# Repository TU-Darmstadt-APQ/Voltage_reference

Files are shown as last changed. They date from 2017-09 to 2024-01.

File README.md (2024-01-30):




# LM399 Sub-ppm Reference Voltage

This repository contains the KiCAD PCB project files for a sub-ppm temperature coefficient __negative voltage reference__ used in the [digital laser driver design](https://github.com/TU-Darmstadt-APQ/DgDrive).

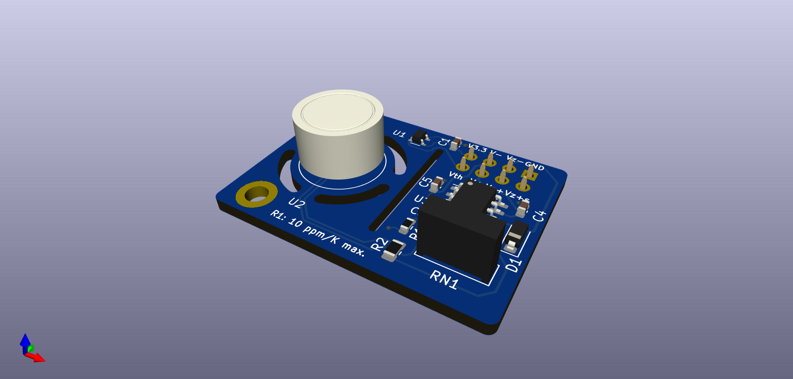
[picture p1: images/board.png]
LM399 reference board


## Circuit description

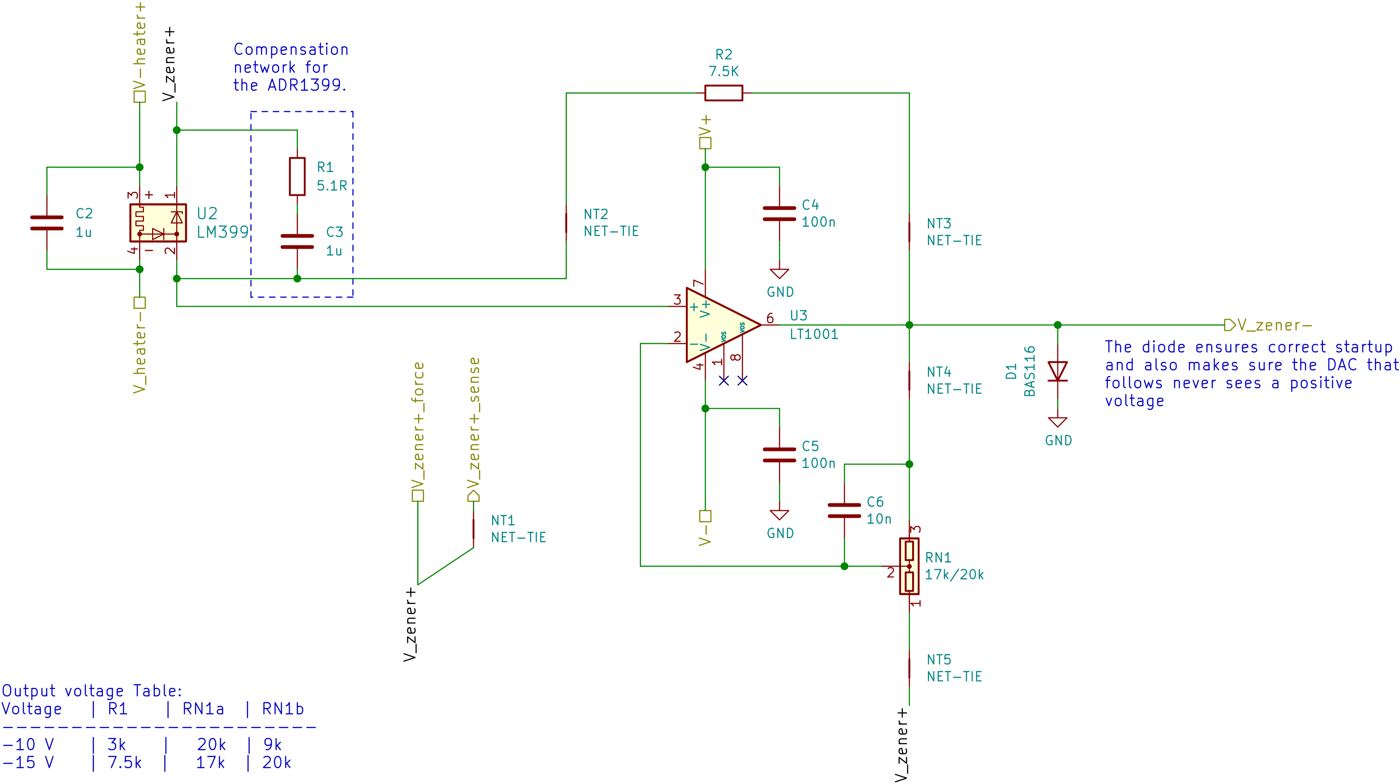
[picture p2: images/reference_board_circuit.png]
LM399 reference board circuit


This circuit utilizes the excellent [LM399](https://www.analog.com/en/products/lm399.html) voltage reference and outputs an amplified voltage of either -10 V or -15 V. There is no option to trim the output voltage as the absolute value is not that important, but stability is. The output voltage will be 10 V / 15 V __below__ the positive pin of the Zener diode.

The design is a self-biased circuit, which means the Zener diode bias current is produced by the Zener voltage and therefore as stable as the reference (neglecting the influence of the bias current on the Zener voltage as it is negligible). In order to keep the Zener self-heating of the diode as low possible, a Zener current of a little more than 1 mA was chosen for the  [LM399](https://www.analog.com/en/products/lm399.html).

Reference table for choosing the resistor values:

|Voltage | R1 | RN1 |
|---|---|---|
|-10 V | 3k | 20k /  9k  |
|-15 V | 7.89k | 17k / 20k |

Different values are possible as well, but these values were readily available on Farnell/Mouser. When choosing a value for R1, choose a value as close as possible but always __less than or equal__ to the value given. This ensures, that the Zener current is at least 1 mA.

Single supply operation is possible as long the output voltage is larger than 0.1 V.

## Design Files
### For production
The design files required for the PCB production and assembly can be found on the [releases](../../releases) page and include the following resources:

- Schematics as a PDF
- Gerber files
- Pick & place position files
- Bill of materials as a CSV file and also as an interactive HTML version

The latest revision of those files can be found [here](../../releases/latest).

#### Variants
Two variants of the design files are provided for the user. There is a so-called *default* variant and a *PCBA* (Printed Circuit Board Assembly) variant.

##### Default variant
The default variant contains the full set of components and should be used for hand assembly when a set of binned and tested components is available. It includes both the Zener reference and resistive divider which need to be tested for popcorn noise and drift before installation.

##### PCBA variant
The PCBA variant should be used when sending the boards to the PCB manufacturer for assembly as they do not contain the [LM399](https://www.analog.com/en/products/lm399.html)/[ADR1399](https://www.analog.com/en/products/adr1399.html) Zener reference and the precision resistor array to amplify the output voltage. These components need to be binned prior to installation and should therefore not be placed by the board house.

### For editing
To work on the [KiCad](https://www.kicad.org/) design files, a number of external libraries are needed. Those libraries show up as empty folders in the zip file, because they are not included in the release, but must be downloaded separately from the links given [below](#related-repositories). This can be avoided by checking out the whole repository using git. This way the libraries will be downloaded as well. Use the following command to clone the git repository along with the submodules  using the `--recurse-submodules` flag.
```
git clone --recurse-submodules https://github.com/TU-Darmstadt-APQ/Voltage_reference
```

## Related Repositories
See the following repositories for more information as these are part of the [design files](#design Files).

- [KiCad footprints](https://github.com/PatrickBaus/footprints.pretty)
- [KiCAD 3D models](https://github.com/PatrickBaus/footprints.3dshapes)
- [KiCAD schematic libraries](https://github.com/PatrickBaus/KiCad-libraries)

## Versioning
I use [SemVer](http://semver.org/) for versioning. For the versions available, see the [tags](../../tags) available for this repository.

- MAJOR versions in this context mean a breaking change to the external interface of the hardware like different connectors or functions.
- MINOR versions contain changes to the hardware that only affect the inner workings of the circuit, but otherwise the performance is unaffected.
- PATCH versions do not affect the schematics or invalidate older bill of materials. These changes may include updated components (to replace obsolete parts for example), an updated silkscreen, or fixed typos.

## License
This work is released under the CERN-OHL-W
See [https://ohwr.org/cern_ohl_w_v2.pdf](https://ohwr.org/cern_ohl_w_v2.pdf) or the included LICENSE file for more information.

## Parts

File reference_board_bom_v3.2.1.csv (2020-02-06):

Component | Quantity Per PCB | References | Value | MFN | PN | Description | Footprint | Note | Alternative
1 | 3 | C1-C3 | 100n | Murata | GRM31C5C1H104JA01L | Unpolarized capacitor | C_1206_3216Metric
2 | 1 | C4 | 100n | Murata | GRM188R71H104KA93D | Unpolarized capacitor | C_0603_1608Metric
3 | 1 | D1 | BAS116 | Nexperia | BAS116GWJ | Diode | D_SOD-123 | Use a plastic package to eliminate light sensitivity
4 | 1 | J1 | CONN_02X04 | Amphenol | 87606-804LF | Generic connector, double row, 02x04, odd/even pin numbering scheme (row 1 odd numbers, row 2 even numbers), script generated (kicad-library-utils/schlib/autogen/connector/) | PinSocket_2x04_P2.54mm_Vertical
5 | 1 | R3 | 10k | Susumu | RR0816P-103-D | Resistor | R_0603_1608Metric
6 | 1 | R2 | 30k | Susumu | RR0816P-303-D | Resistor | R_0603_1608Metric
7 | 1 | R1 | 7.5K | Welwyn | PCF0805-13-7K5-B-T1 | Resistor | R_0805_2012Metric |  | Panasonic ERA-6ARB752V
8 | 1 | RN1 | 17k/20k | Vishay | Y1691V0689BB9L | Voltage divider | Vishay_300144 | Vishay 300144Z, 0.1% abs. tol. 0.1% ratio tol.
9 | 1 | U2 | LM399 | Analog Devices | LM399AH | Precision Reference, 6.95V, Buried Zener Diode with Thermal Shielding Can | TO-46-4_ThermalShield | Use a TE 8060-1G12 socket to mount diodes for burn-in
10 | 1 | U3 | LT1001 | Analog Devices | LT1001CS8 | 70MHz, 1000V/µs Operational Amplifier, DIP-8/SOIC-8 | SOIC-8_3.9x4.9mm_P1.27mm |  | TI OPA277U
11 | 1 | U1 | TMP236 | Texas Instruments | TMP236A2DCKT | Analog thermistor temperature sensor, ±2.5C accuracy, -55C to +130C, SC-70-5 | SOT-353_SC-70-5
Component Groups: | 11
Component Count: | 13
Fitted Components: | 13
Number of PCBs: | 1
Total components: | 13
Schematic Version: | v3.2.1
Schematic Date: | 2020-02-06
PCB Variant: | default
BoM Date: | 2020-02-06T17:09:21 CET
Schematic Source: | /home/maat/Documents/Uni/Physik/Phd/DgDrive/KiCAD/reference_board/reference_board.sch
KiCad Version: | Eeschema 5.1.5

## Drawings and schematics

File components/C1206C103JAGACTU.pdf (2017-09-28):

# KEMET Part Number: C1206C103JAGACTU

# (C1206C103JAGAC7800)

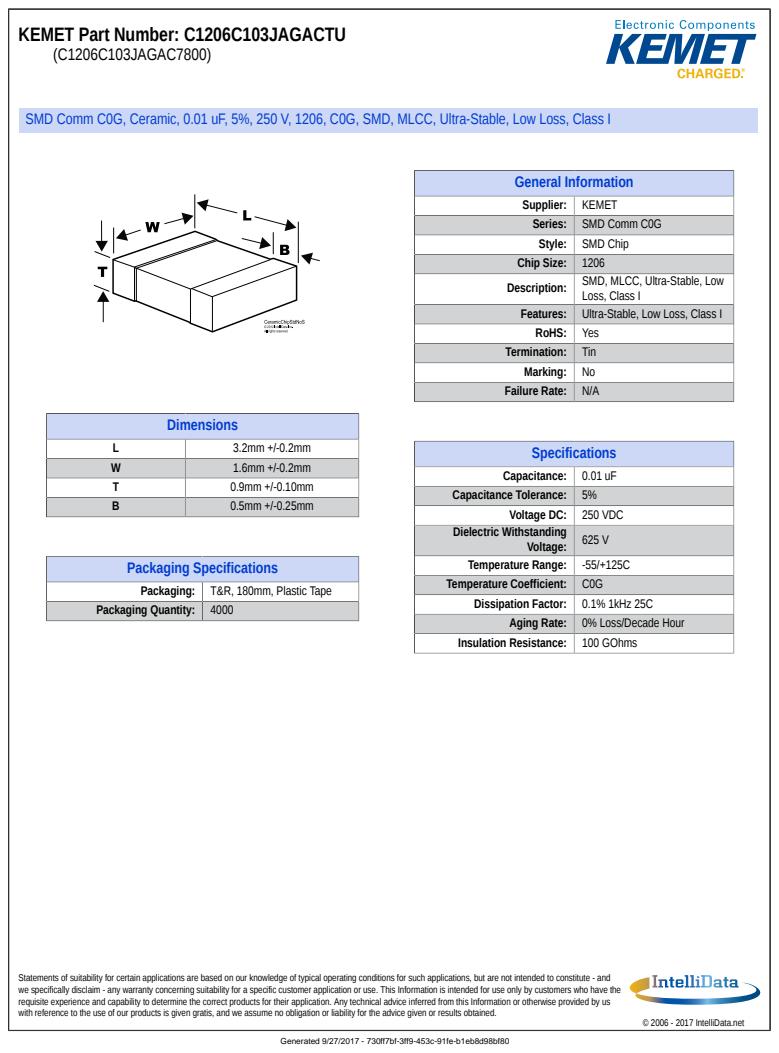
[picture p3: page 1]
Generated 9/27/2017 - 730ff7bf-3ff9-453c-91fe-b1eb8d98bf80; Dimensions; Packaging Specifications; General Information; Specifications; Temperature Range:; © 2006 - 2017 IntelliData.net

SMD Comm C0G, Ceramic, 0.01 uF, 5%, 250 V, 1206, C0G, SMD, MLCC, Ultra-Stable, Low Loss, Class I

Supplier: | KEMET
Series: | SMD Comm C0G
Style: | SMD Chip
Chip Size: | 1206
Description: | SMD, MLCC, Ultra-Stable, Low Loss, Class I

Features: | Ultra-Stable, Low Loss, Class I
RoHS: | Yes
Termination: | Tin
Marking: | No
Failure Rate: | N/A

W 1.6mm +/-0.2mm
T 0.9mm +/-0.10mm
B 0.5mm +/-0.25mm

Capacitance: | 0.01 uF

Capacitance Tolerance: | 5%

Voltage DC: | 250 VDC

Dielectric Withstanding Voltage: | 625 V

Packaging: | T&R, 180mm, Plastic Tape
Packaging Quantity: | 4000

Temperature Coefficient: | C0G
Dissipation Factor: | 0.1% 1kHz 25C
Aging Rate: | 0% Loss/Decade Hour

Insulation Resistance: | 100 GOhms

Statements of suitability for certain applications are based on our knowledge of typical operating conditions for such applications, but are not intended to constitute - and
we specifically disclaim - any warranty concerning suitability for a specific customer application or use. This Information is intended for use only by customers who have the
requisite experience and capability to determine the correct products for their application. Any technical advice inferred from this Information or otherwise provided by us
with reference to the use of our products is given gratis, and we assume no obligation or liability for the advice given or results obtained.

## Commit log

2017-08-21 Updated readme with a circuit description Fixed typo on the schematic Added datasheet of LM399
    [LM399.sch]
2017-08-26 Fixed R1 (3k) resistor part number Updated .gitignore file
    [LM399.sch]
2017-08-27 Added license
    [LM399.sch]
2017-08-27 Moved around some text to make it easier to read
    [reference_board.kicad_pcb]
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2017-09-28 Positive zener pin now has a sense connection to correct fot the error caused by the 1 mA zener current Changed zener bias current resistor to less expensive smd precision resistor Added a 2nd parall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
    [BOM.csv, LM399.sch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]
2018-01-06 Reduced board size Changed voltage divider to Vishay 300144Z Removed guard ring Added startup resistor R5 Changed all capacitors to 100 nF C0G
    Updated modules
    [LM399.sch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]
2018-01-06 Updated picture Updated annotations
    [LM399.sch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]
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2018-08-17 Updated schematic to KiCAD v5 Reduced board size even further by replacing the AD590 with a TMP236
    [BOM.csv, LM399.sch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]
2018-08-18 Updated component datasheets
    [BOM.csv, LM399.sch, reference_board.sch]
2018-08-18 Fixed positin of U3 label
    [reference_board.kicad_pcb]
2018-08-18 Fixed pin labels
    [reference_board.kicad_pcb]
2018-08-18 Update README.md
    Updated the value name of the gain resistor, because we are now using a resistor network
2018-08-18 Updated version number to 3.0
    [LM399.sch, reference_board.kicad_pcb, reference_board.sch]
2018-10-04 Update to version 3.0 (compatible with the current driver RC2) Replaced the chopper amplifier with the LT1001 Updated the libraries
    [LM399.sch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]
2018-10-04 Updated BOM
    [BOM.csv]
2019-01-10 Added M2.5 mounting hole Updated to v3.1
    [LM399.sch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]
2019-01-10 Updated mounting hole footprint
    [reference_board.kicad_pcb]
2019-01-10 Increased footprint size of R1 from 0603 to 0805
    [LM399.sch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]
2019-01-10 Added pin socket MFP
    [BOM.csv]
2019-02-19 Changed trace width to 0.25 mm to make it more robust Added bypass capacitor to the temperature sensor Rotated open source logo to fit it onto the board
    [LM399.sch, reference_board.kicad_pcb, reference_board.sch]
2019-02-19 Updated Gerber filer
    [reference_board-B_Cu.gbr, reference_board-B_Mask.gbr, reference_board-B_SilkS.gbr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]
2019-02-19 Updated the LM399 footprint to match the KiCAD guidelines
    [LM399.sch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]
2019-03-05 Fixed gerber files. The latet version of KiCAD uses a different naming scheme. Removed duplicates.
    [reference_board-B.Cu.gbr, reference_board-B.Mask.gbr, reference_board-B.SilkS.gbr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]
2019-03-05 Added drill files to gerber files
    [reference_board-NPTH.drl, reference_board-PTH.drl]
2019-06-28 Updated resistor requirements (changed R1 from 5 ppm to 10 ppm) Rotated all text labels by 180° to match the main pcb Fixed soldermask to preventsolder from shorting rectangular pins to GND
    [LM399.sch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]
2019-11-08 Removed via from bypass capacitor pad
    [LM399.sch, reference_board.kicad_pcb, reference_board.sch]
2019-11-08 Updated to v3.1.2 Added part number of the socket (optional)
    [LM399.sch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]
2019-11-17 Updated libraries Inverted back side voltage and serial number label Fixed 3D viewer by increasing the arc cutout coordinate resoultion to 4 digits after the decimal (from 2)
    [reference_board-B_Cu.gbr, reference_board-B_Mask.gbr, reference_board-B_SilkS.gbr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]
2020-01-28 Changed op amp to LT1001 Added startup circuit Board shrink Changed temperature sensor to TI TMP236 Added mounting hole
    [LM399.sch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]
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2020-01-28 Updated schematic images
    [LM399.sch, reference_board.sch]
2020-02-06 Updated to v.3.2.1 -Changed D1 to a plastic package to eliminate possible light sensitivity -Updated bom.ini for the latest version of KiBOM -Updated symbol fields (changed MFP -> PN) for KiCost comp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
    [BOM.csv, LM399.sch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]
2020-09-28 Updated footprints and 3d models in preparation for KiCAD 5.1.7 (which contains an LM399 footprint, see https://github.com/KiCad/kicad-footprints/pull/2481)
    [LM399.sch, reference_board.kicad_pcb, reference_board.sch]
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2020-09-28 Updated Gerber files
    [reference_board-B_Cu.gbr, reference_board-B_Mask.gbr, reference_board-B_SilkS.gbr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]
2020-09-28 Fixed U2 label
    [reference_board-B_Cu.gbr, reference_board-B_Mask.gbr, reference_board-B_SilkS.gbr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]
2021-02-25 Added ibom Simplified RN1 description Moved R2 a little bit away from R3 to prevent problems during soldering
    [LM399.sch, reference_board.kicad_pcb]
2021-02-25 Renamed BOM
    [reference_board_bom_v3.2.2.csv]
2021-02-25 Remvoed solder mask clearance Updated gerber files
    [reference_board-B_Cu.gbr, reference_board-B_Mask.gbr, reference_board-B_SilkS.gbr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]
2021-05-20 Replaced startup circuit with a JFET
    [LM399.sch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]
2021-05-20 Added part annotations
    [LM399.sch, reference_board.kicad_pcb]
2021-05-20 Fixed typo
    [LM399.sch]
2023-11-25 Updated to KiCad 7 Added CI pipeline
    [LM399.kicad_sch, LM399.sch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]
2023-11-25 Cleaned up old files
    [reference_board.sch]
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2023-11-25 Add PCBA variant
    [LM399.kicad_sch, reference_board.kicad_pcb]
2023-11-26 Added paste layer
    [reference_board.kicad_pcb]
2023-11-26 Updated license
    [LM399.kicad_sch, reference_board.kicad_sch]
2023-11-27 Cleanup: removed Gerber files from git. These can be found with the release
    [reference_board-B_Cu.gbr, reference_board-B_Mask.gbr, reference_board-B_Silkscreen.gbr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]
2023-11-30 Added RoHS log and APQ logo
    [reference_board.kicad_pcb, reference_board.kicad_sch]
2023-11-30 Updated libs
    [reference_board.kicad_pcb]
2023-11-30 Updated library
    [reference_board.kicad_pcb]
2023-12-01 Updated libraries
    [LM399.kicad_sch, reference_board.kicad_pcb]
2023-12-04 Bump libraries from `a75535c` to `50896b9`
    Bumps [libraries](https://github.com/PatrickBaus/KiCad-libraries) from `a75535c` to `50896b9`.
    - [Commits](https://github.com/PatrickBaus/KiCad-libraries/compare/a75535c8cde1aeacfd696481e12f5a4dff228cb8...50896b91e8f923cd095306b51fce827216ea2790)
    ---
    updated-dependencies:
    - dependency-name: libraries
    dependency-type: direct:production
    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
2023-12-04 Bump footprints.pretty from `466b25d` to `3b08aea`
    Bumps [footprints.pretty](https://github.com/PatrickBaus/footprints.pretty) from `466b25d` to `3b08aea`.
    - [Commits](https://github.com/PatrickBaus/footprints.pretty/compare/466b25d2836033a0aa6c1dfcbf0ba5bedb93b2f0...3b08aea06782ccf893a1a138df3cad022f2d500a)
    - dependency-name: footprints.pretty
    ...
    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
2024-01-30 Bumped version to 3.4.1 Updated libs Added more tests regarding the version to the CI
    [LM399.kicad_sch, reference_board.kicad_pcb, reference_board.kicad_sch]
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2024-07-30 Updated to KiCad 8 (#36)
    * Updated to KiCad 8
    * Updated Kibot config to new format
    [LM399.kicad_sch, reference_board.kicad_pcb, reference_board.kicad_sch]
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

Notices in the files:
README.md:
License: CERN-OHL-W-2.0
